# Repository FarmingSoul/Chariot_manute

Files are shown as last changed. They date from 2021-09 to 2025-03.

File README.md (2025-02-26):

# Projet du chariot de manutention
01/09/2021

Ce chariot de manutention à 2 roues centrales. Ce qui lui permet de transporter du poids sans l'aide de l'utilisateur-rice, qui n' a ici plus que le déplacement à gérer.

Ce chariot fut proposé comme solution à une demande de déplacement de poids et volume avec le moindre effort.

chariot

* la surface utile est 200X60 (pour 5 caisse de 60X40 par étage)
* Il y a un tableau à l'avant et des blocages de part et d'autre afin de sécuriser le chargement
* Les roues sont des roues increvables
* Le modèle est paramétrable à la taille de l'utilisateur pour un confort optimal

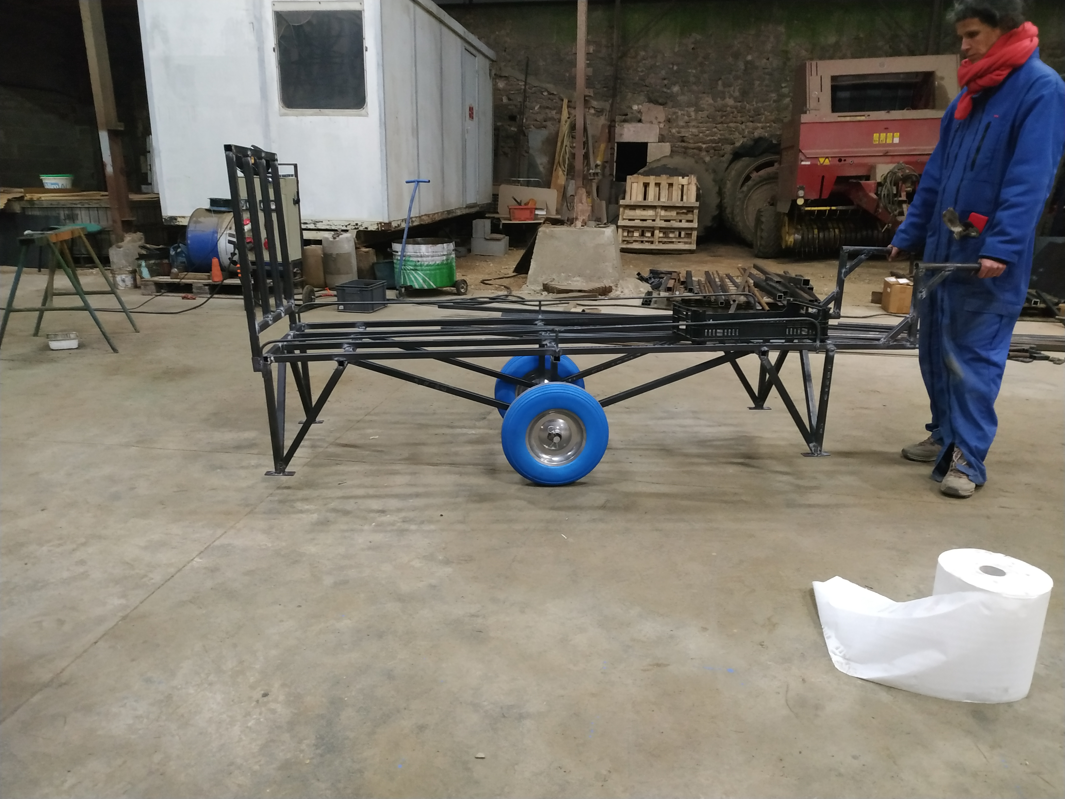
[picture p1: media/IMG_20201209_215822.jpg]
chariot2


# Feuille de route

* modéliser l'outil (fait)
* faire les plans (en cours)
* produire une nomenclature (fait)
* proposé une fiche de débit
* prototyper l'outil (fait)
* média (en cours)
* retours utilisateurs-trices (en cours-dans l'onglet issue)

## pour ouvrir ce modèle sous FreeCAD il est possible que vous ayez besoin du Mod FS
### https://github.com/FarmingSoul/FreeCAD_Mod_FS

### https://FARMINGSOUL.ORG

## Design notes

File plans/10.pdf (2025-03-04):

01/03/25 | 10/16

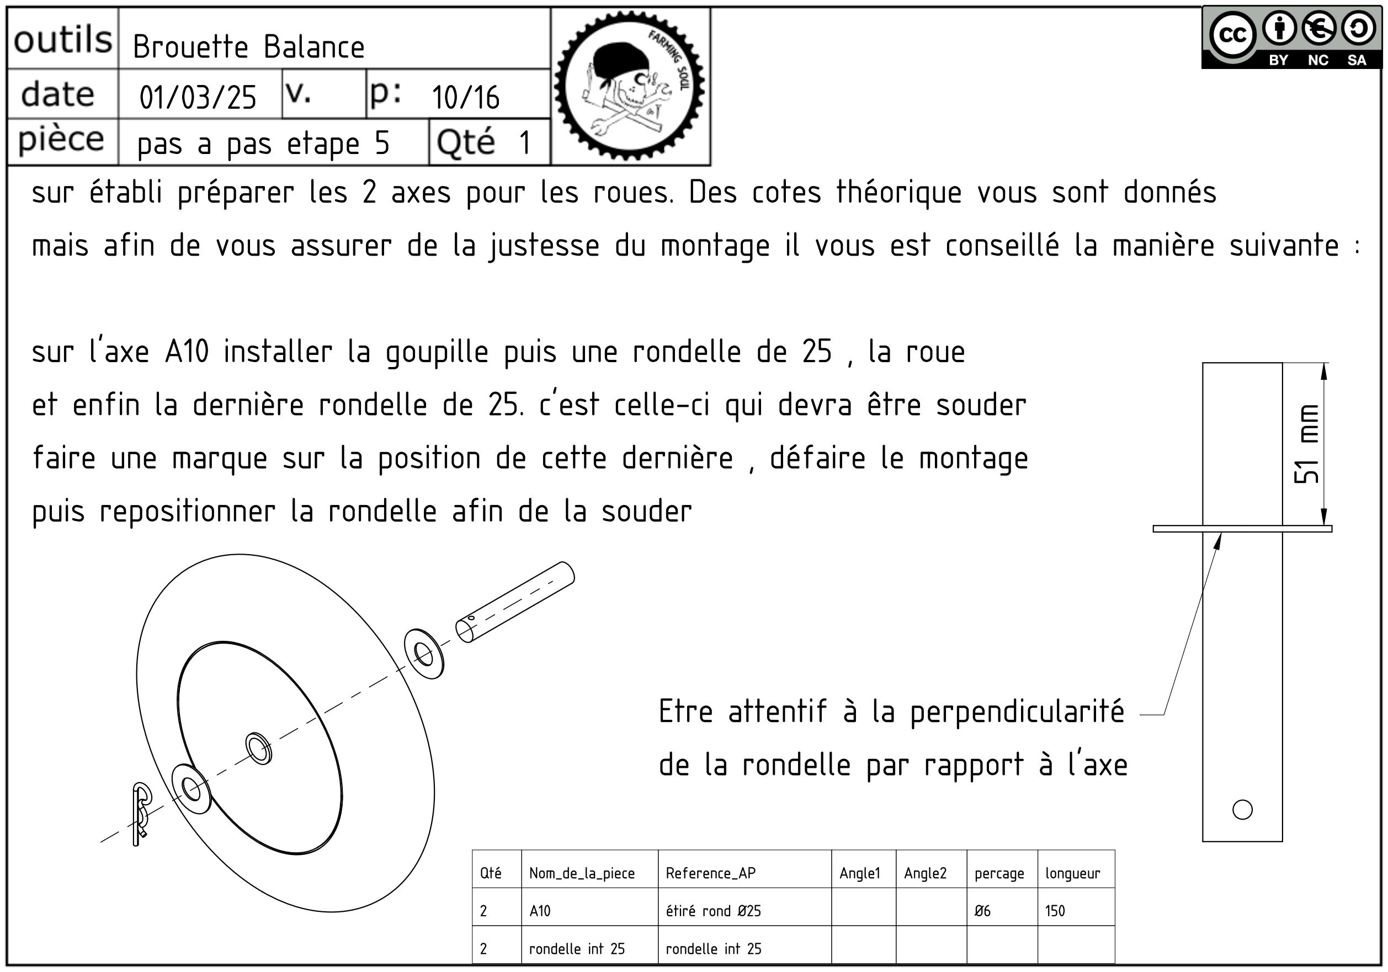
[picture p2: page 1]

51 m

m

sur établi préparer les 2 axes pour les roues. Des cotes théorique vous sont donnés

mais afin de vous assurer de la justesse du montage il vous est conseillé la manière suivante :

sur l'axe A10 installer la goupille puis une rondelle de 25 , la roue

et enfin la dernière rondelle de 25. c'est celle-ci qui devra être souder

faire une marque sur la position de cette dernière , défaire le montage

puis repositionner la rondelle afin de la souder

Brouette Balance

pas a pas etape 5 | 1

Etre attentif à la perpendicularité

de la rondelle par rapport à l'axe

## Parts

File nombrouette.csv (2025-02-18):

Nom_de_la_piece | Reference_AP | Angle1 | Angle2 | percage | longueur | Qty.
A2 | Tube carré 25 x 2 |  |  |  | 610 | 4
A1 | Tube carré 25 x 2 |  |  |  | 2285 | 2
A3 | fer rond Ø10 |  |  |  | 2140 | 2
A4 | fer rond Ø10 |  |  |  | 90 | 2
A5 | Tube carré 25 x 2 |  |  |  | 258.5 | 2
A6 | Tube carré 25 x 2 |  |  |  | 420 | 1
A7 | Tube carré 25 x 2 |  |  |  | 1960 | 2
A8 | Tube carré 25 x 2 |  |  |  | 560 | 1
A9 | Tube carré 25 x 2 |  |  |  | 215 | 2
A12 | Tube carré 25 x 2 |  |  |  | 400 | 4
A13 | Tube carré 25 x 2 | 33.49 | 56.51 |  | 449.6463198543509 | 4
A14 | Tube carré 25 x 2 | 19.66 | 19.66 |  | 772.8352494190133 | 4
A11 | UPN 30 x 15 |  |  |  | 46 | 2
A10 | fer rond Ø25 |  |  |  | 150 | 2
roue | Roue increvable Ø389 Øaxe25 L 82 |  |  |  |  | 2
A15 | Tube carré 25 x 2 | 30.03 | 59.97 |  | 462 | 4
A16 | Tube carré 30 x 2 |  |  |  | 50 | 2
BB1 | Tube carré 25 x 2 |  |  |  | 685 | 2
BB2 | Tube carré 25 x 2 |  |  |  | 560 | 4
A17 | Tube rond 30 x 2 |  |  |  | 300 | 2
A18 | Tube carré 25 x 2 | 45 | 45 |  | 142 | 4
rondelle 25 | rondelle 25 |  |  |  |  | 4
goupille elastique 5 x 80 | goupille elastique 5 x 80 |  |  |  |  | 2

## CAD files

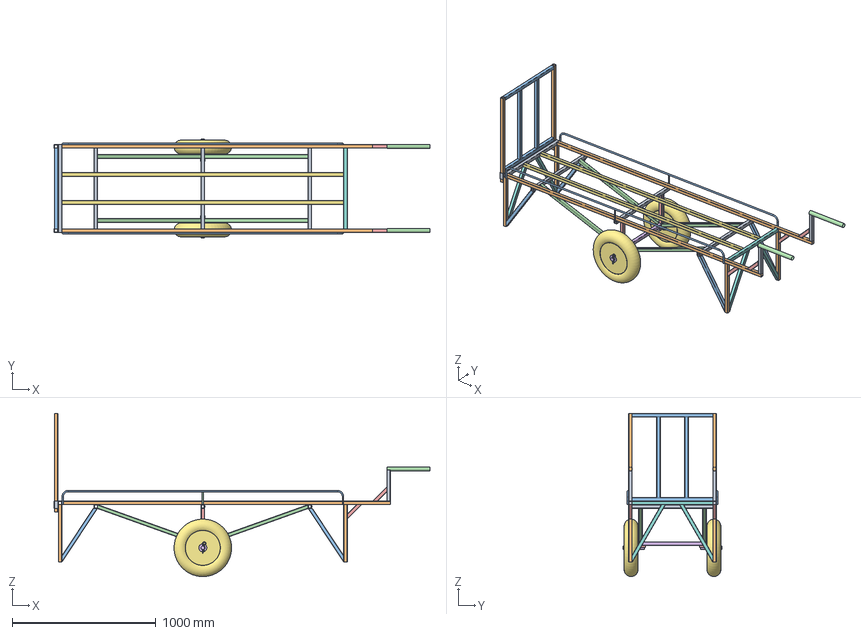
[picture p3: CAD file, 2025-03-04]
brouetteas4-am.FCStd
2615.0 x 688.0 x 1135.0 mm
A8004 x 2
rondellle x 4
goupille x 2

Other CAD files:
brouetteas4.FCStd

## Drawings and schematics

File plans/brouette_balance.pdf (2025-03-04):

2615 mm

01/03/25 | 1/16

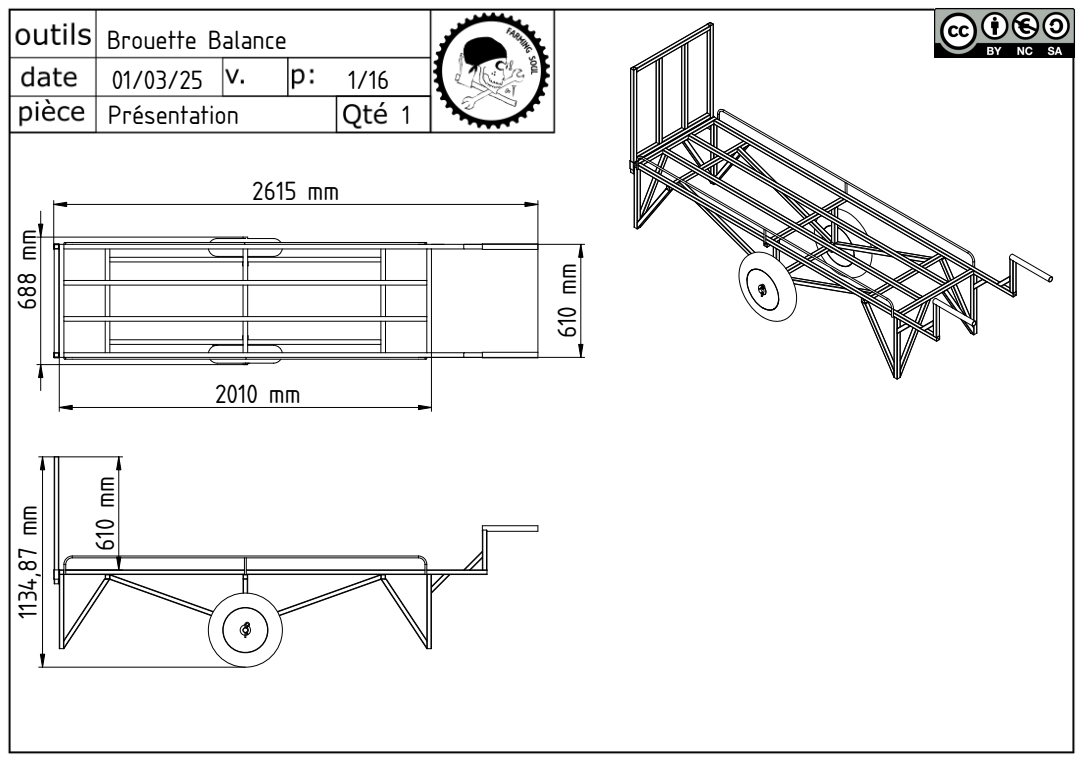
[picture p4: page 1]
Brouette Balance; Présentation

01/03/25 | 2/16

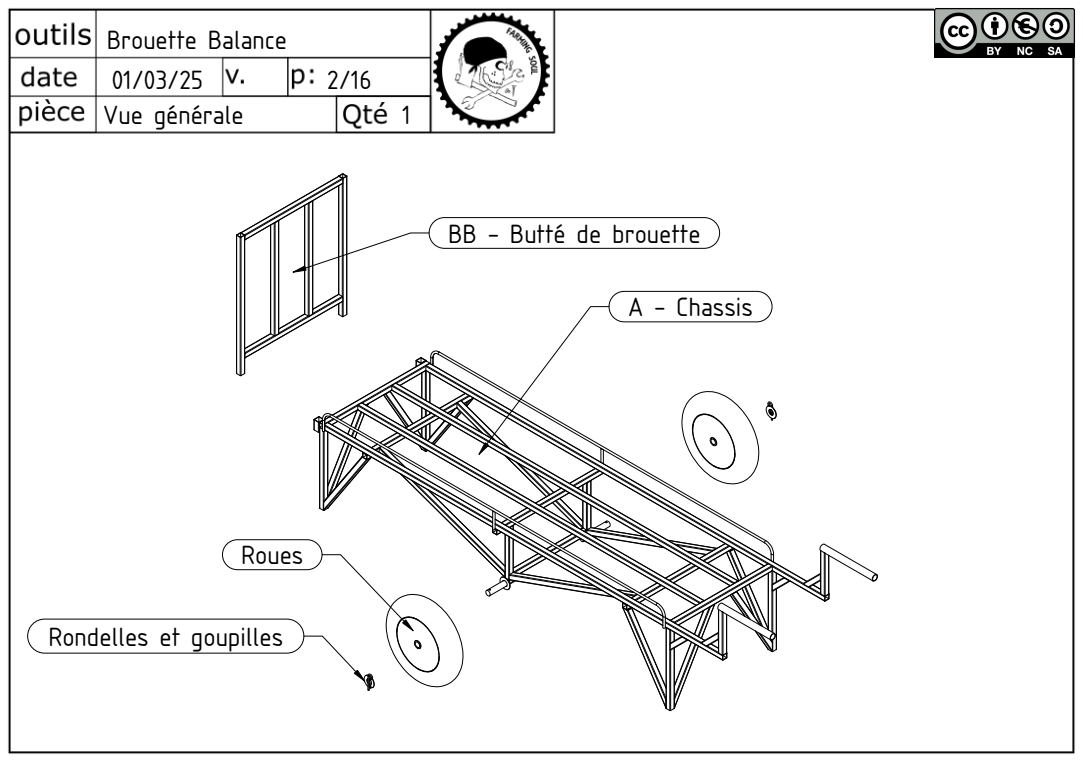
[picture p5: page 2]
A - Chassis; Roues; Vue générale

BB - Butté de brouette

Rondelles et goupilles

A7

01/03/25 | 3/16

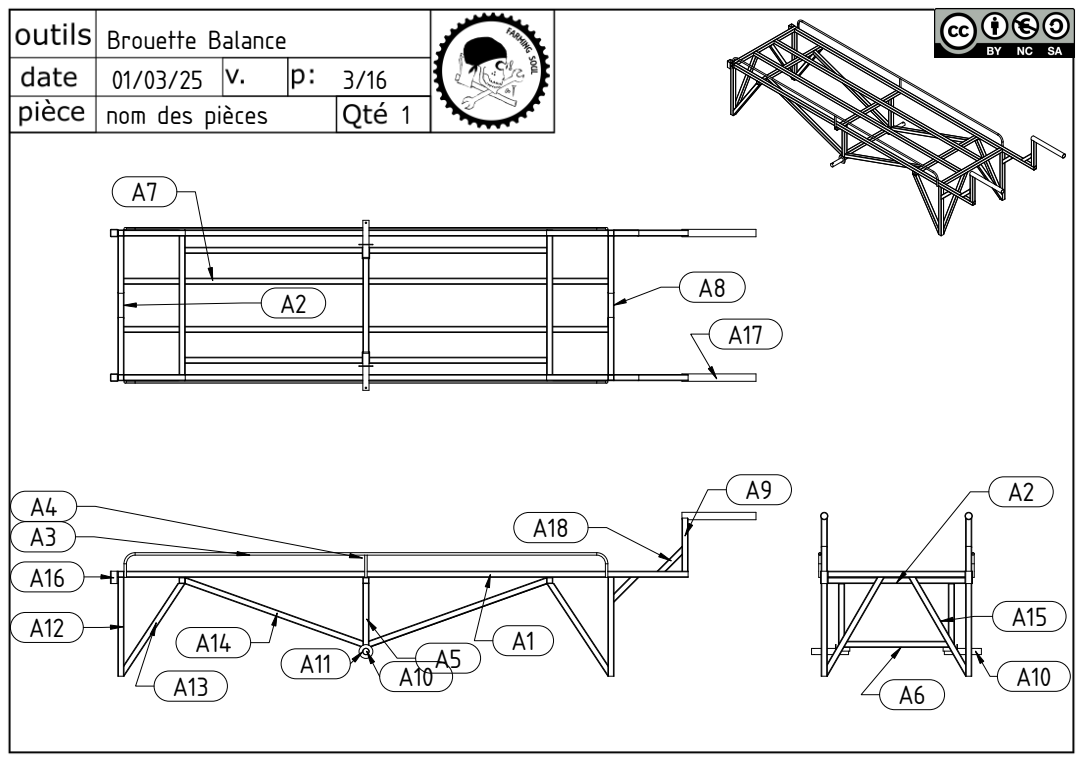
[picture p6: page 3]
nom des pièces

248 mm
992,5 mm

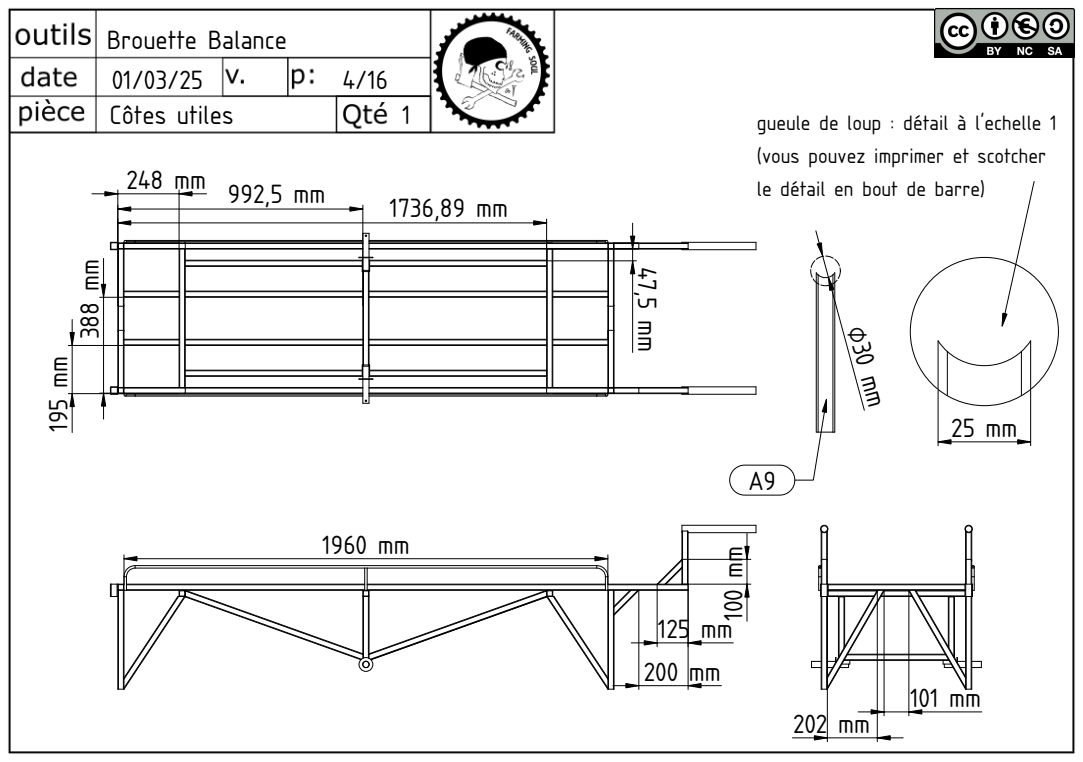
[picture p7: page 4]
Côtes utiles

gueule de loup : détail à l'echelle 1

(vous pouvez imprimer et scotcher

le détail en bout de barre)

195 mm

01/03/25 | 5/16

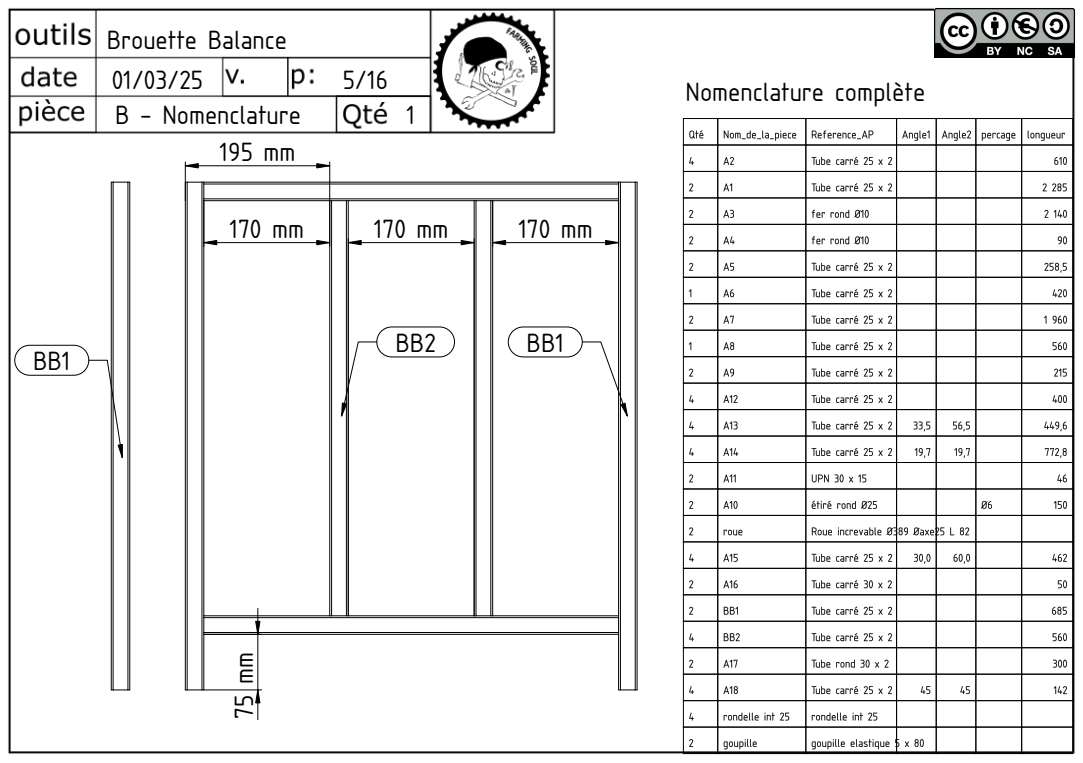
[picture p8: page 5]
Nomenclature complète; B - Nomenclature

A | A8

1

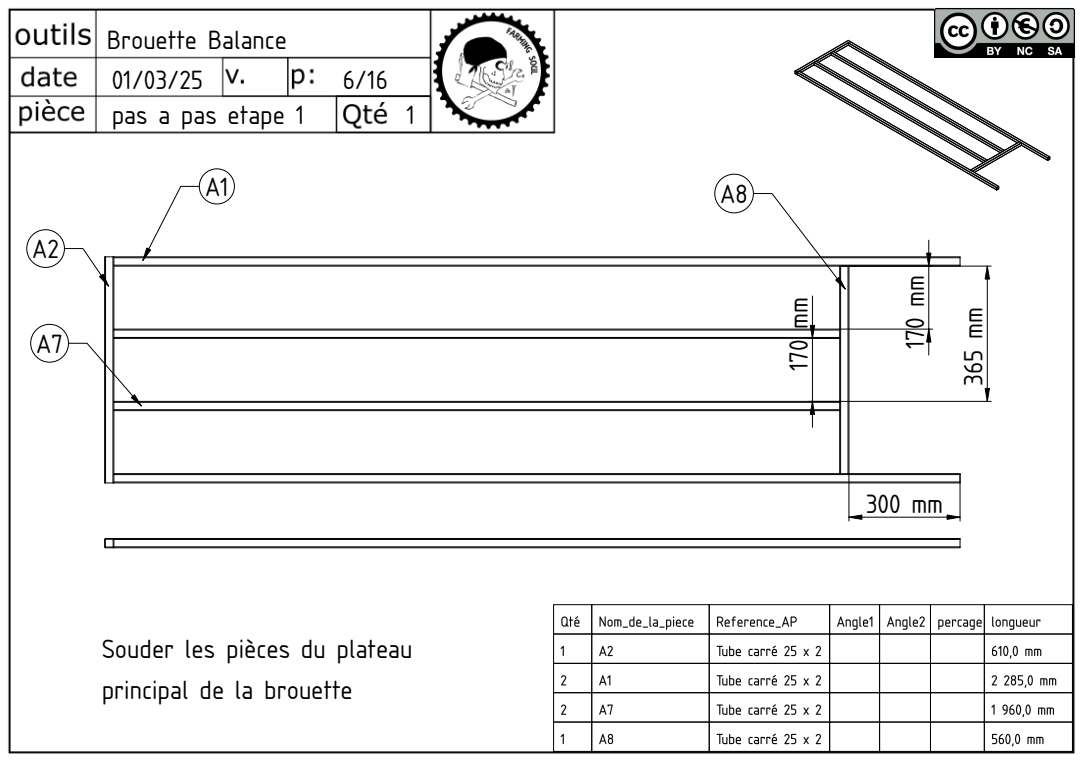
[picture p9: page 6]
pas a pas etape 1

Souder les pièces du plateau

principal de la brouette

01/03/25 | 7/16

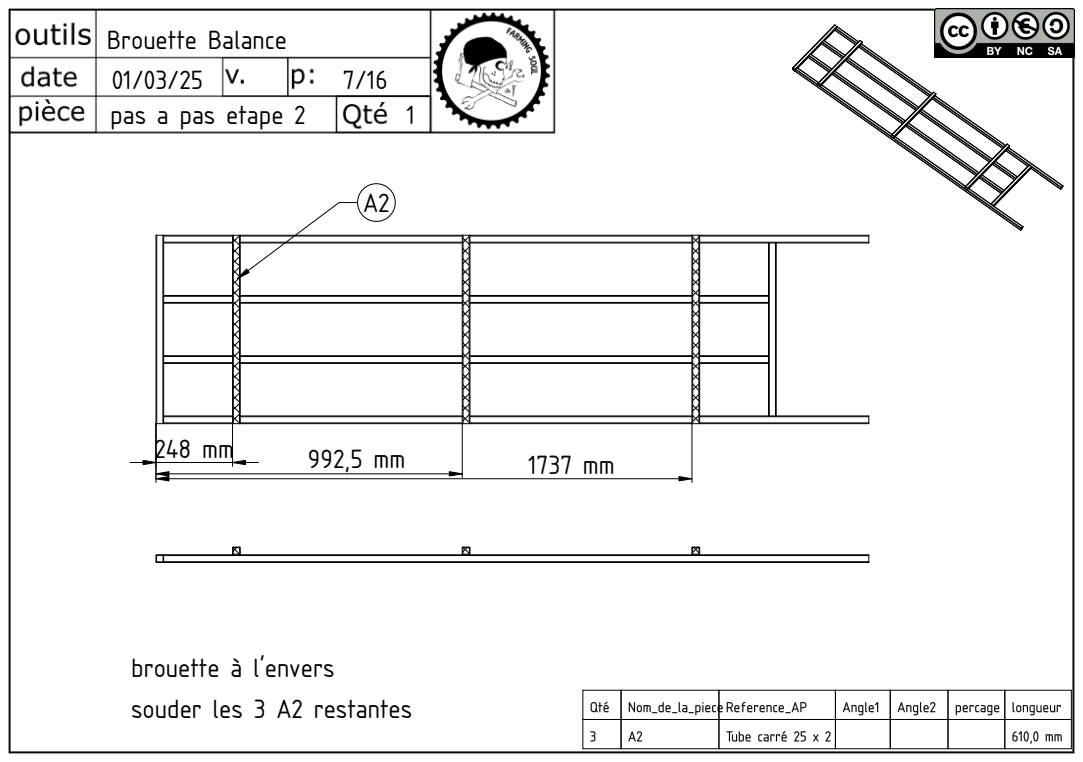
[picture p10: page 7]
brouette à l'envers; pas a pas etape 2

souder les 3 A2 restantes

01/03/25 | 8/16

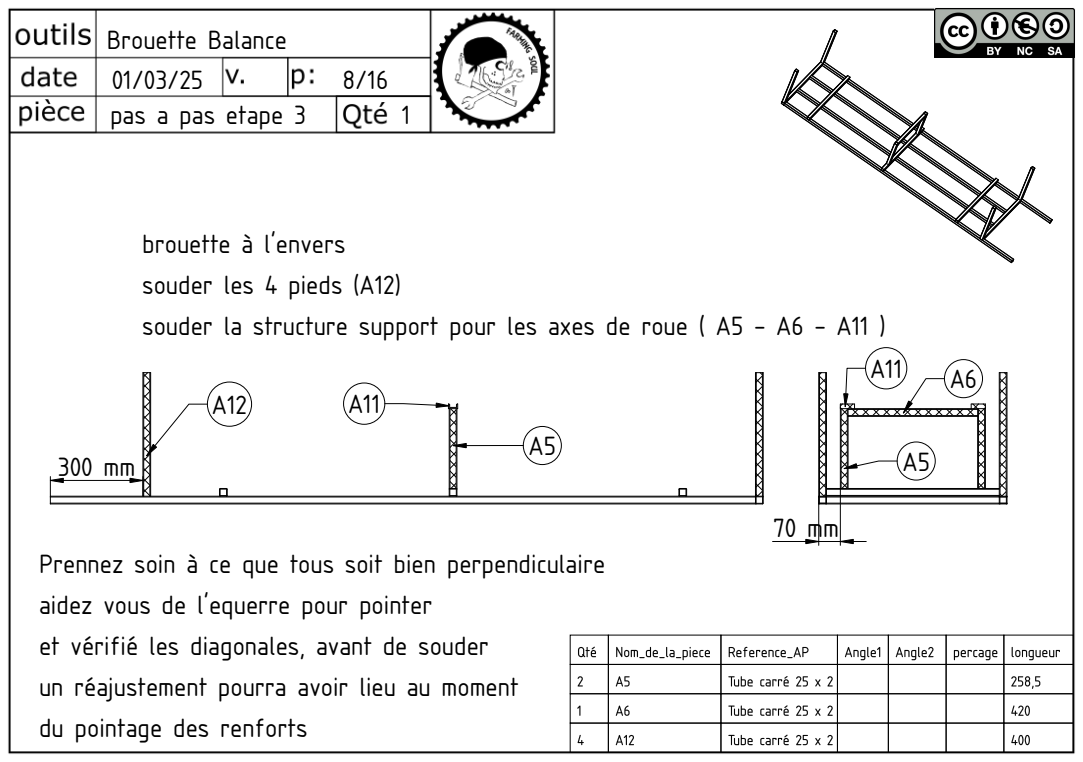
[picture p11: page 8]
brouette à l'envers; pas a pas etape 3

souder les 4 pieds (A12)

souder la structure support pour les axes de roue ( A5 - A6 - A11 )

Prennez soin à ce que tous soit bien perpendiculaire

aidez vous de l'equerre pour pointer

et vérifié les diagonales, avant de souder

un réajustement pourra avoir lieu au moment

du pointage des renforts

01/03/25 | 9/16

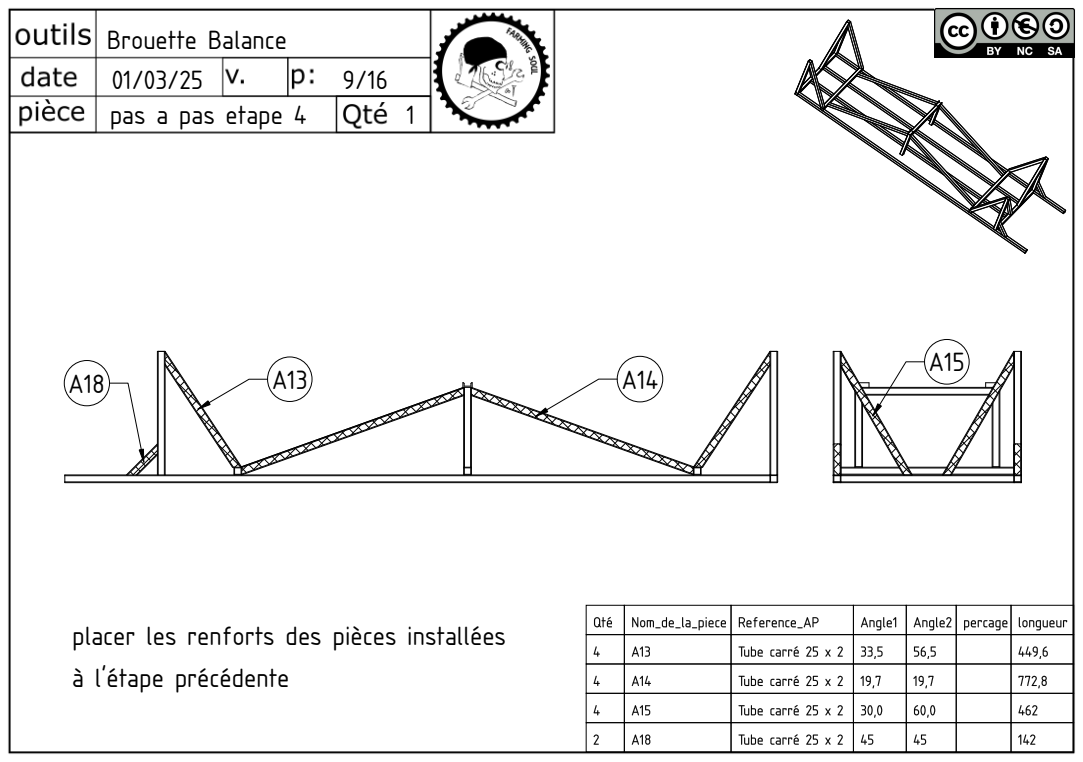
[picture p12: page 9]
à l'étape précédente; pas a pas etape 4

placer les renforts des pièces installées

sur établi préparer les 2 axes pour les roues. Des cotes théorique vous sont donnés

mais afin de vous assurer de la justesse du montage il vous est conseillé la manière suivante :

sur l'axe A10 installer la goupille puis une rondelle de 25 , la roue

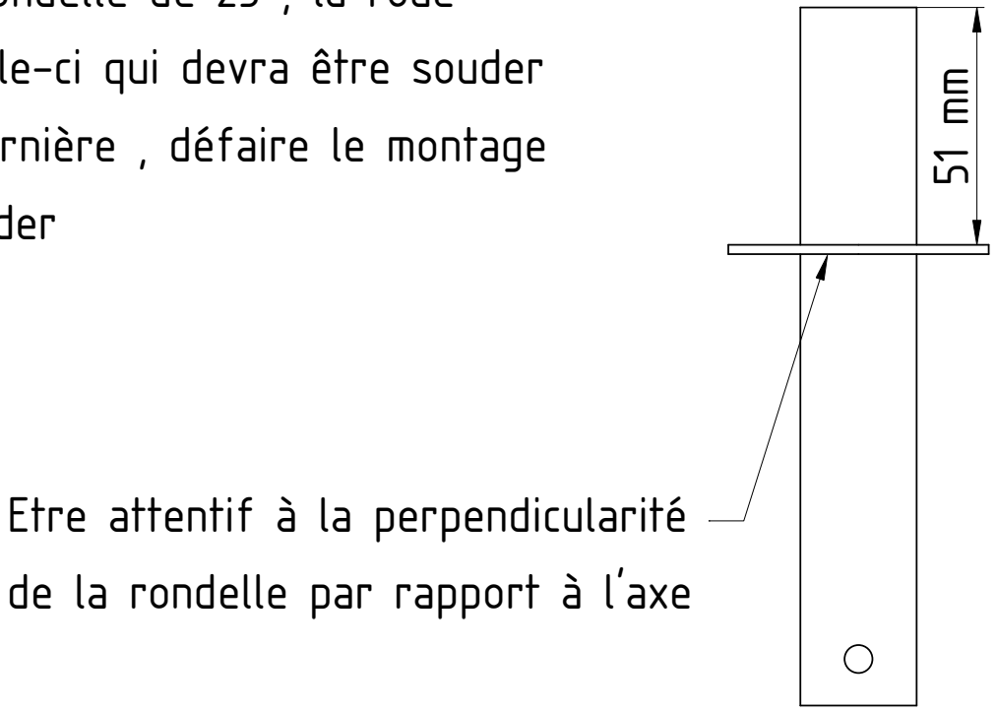
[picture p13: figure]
Etre attentif à la perpendicularité; de la rondelle par rapport à l'axe

et enfin la dernière rondelle de 25. c'est celle-ci qui devra être souder

faire une marque sur la position de cette dernière , défaire le montage

puis repositionner la rondelle afin de la souder

01/03/25 | 10/16
pas a pas etape 5 | 1

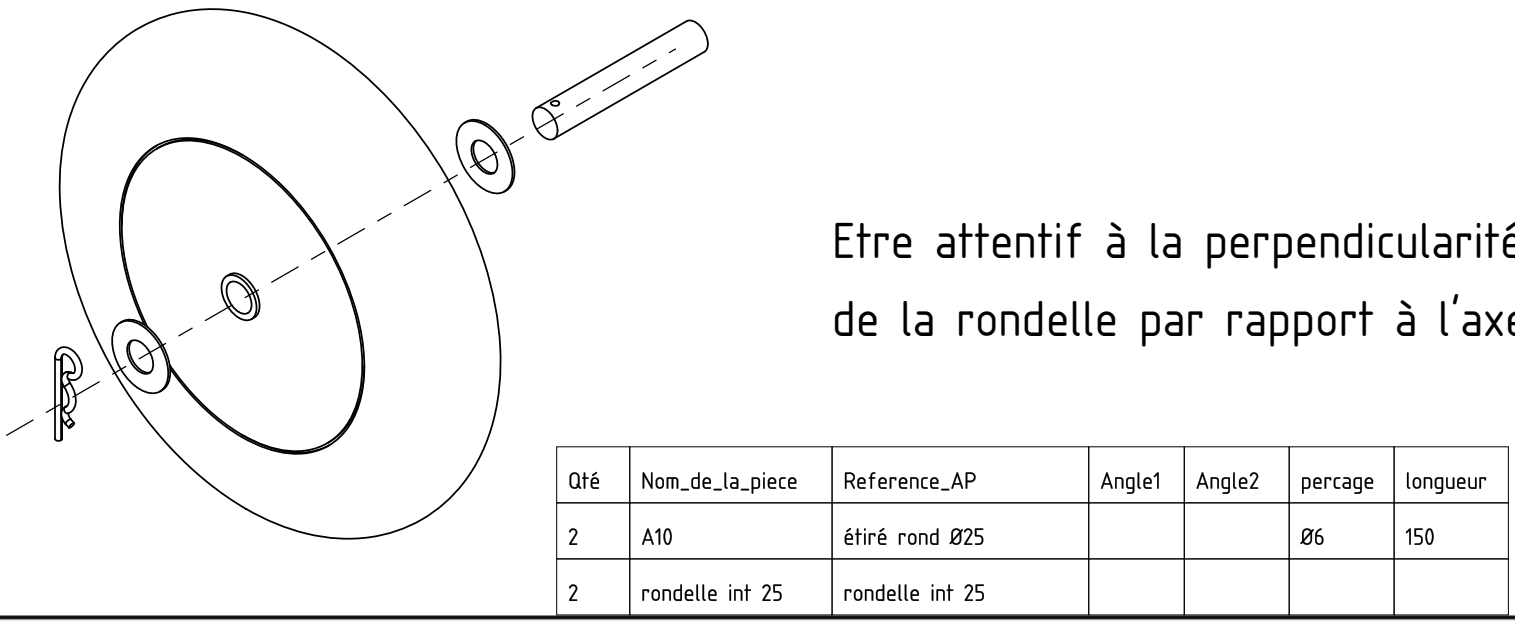
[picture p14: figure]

01/03/25 | 11/16

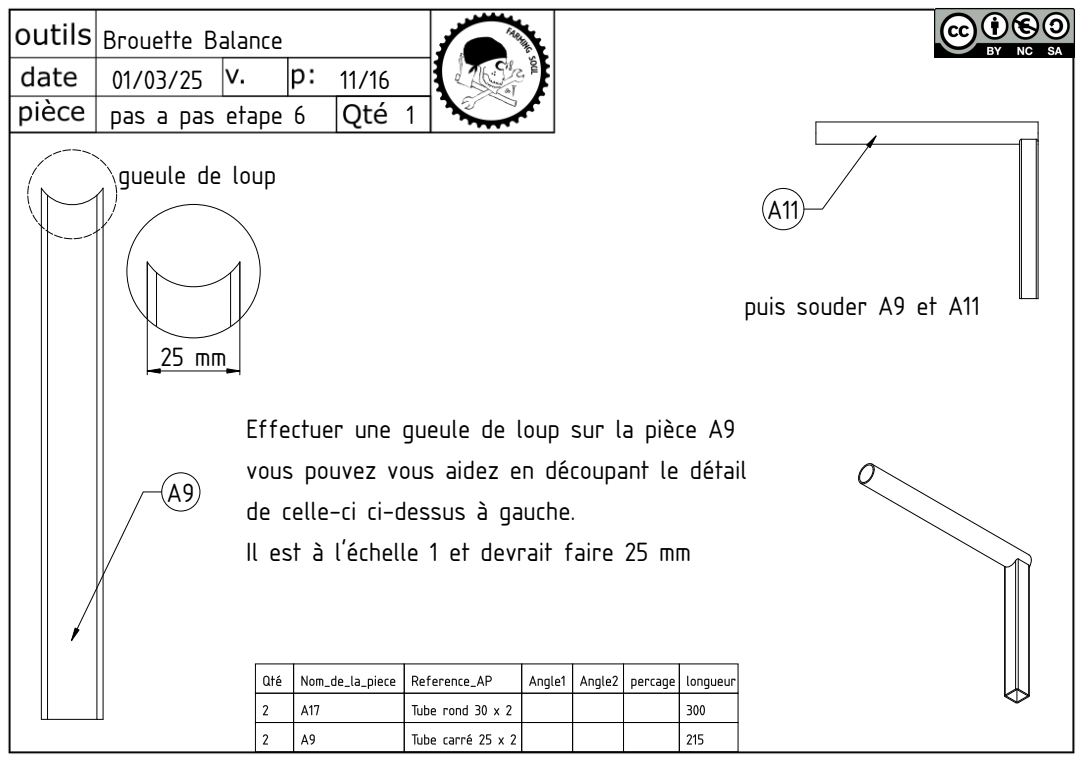
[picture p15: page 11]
pas a pas etape 6

gueule de loup

puis souder A9 et A11

Effectuer une gueule de loup sur la pièce A9

vous pouvez vous aidez en découpant le détail

de celle-ci ci-dessus à gauche.
Il est à l'échelle 1 et devrait faire 25 mm

01/03/25
12/16

zoom

pas a pas etape 7

souder les 2 axes de roue préparés précédement
sur les UPN A10

Respecter un espacement

de 10 mm entre
le bout de la pièce A10

Axe de roue

et la rondelle

1960 mm
1870 mm

précédement construitent; pas a pas etape 8

Souder les poignets

ainsi que leurs renforts

tordre A3 puis souder A3 et A4

sur les paroies exterieur de la brouette

01/03/25 | 14/16

pas a pas etape 9

souder les pièces du fond de la brouette

01/03/25 | 15/16

puis soudez; pas a pas etape 10

pointez les pièces A16

puis installez le fond de brouette

afin de vous assurez que

les pièces A16 soient au bon endroit

01/03/25 | 16/16

maintenant opérationel !; pas a pas etape 11

Il ne vous reste plus qu'a installer les roues - rondelles - goupilles

Votre brouette est

S'il vous plait faite

nous des retours :

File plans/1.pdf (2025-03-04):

2615 mm

01/03/25 | 1/16

Brouette Balance; Présentation

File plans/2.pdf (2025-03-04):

01/03/25 | 2/16

A - Chassis; Roues; Brouette Balance; Vue générale

BB - Butté de brouette

Rondelles et goupilles

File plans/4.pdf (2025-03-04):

248 mm
992,5 mm

Brouette Balance; Côtes utiles

gueule de loup : détail à l'echelle 1

(vous pouvez imprimer et scotcher

le détail en bout de barre)

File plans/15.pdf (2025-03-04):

01/03/25 | 15/16

puis soudez; Brouette Balance; pas a pas etape 10

pointez les pièces A16

puis installez le fond de brouette

afin de vous assurez que

les pièces A16 soient au bon endroit

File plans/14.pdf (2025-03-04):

01/03/25 | 14/16

Brouette Balance; pas a pas etape 9

souder les pièces du fond de la brouette

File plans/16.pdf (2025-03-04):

01/03/25 | 16/16

maintenant opérationel !; Brouette Balance; pas a pas etape 11

Il ne vous reste plus qu'a installer les roues - rondelles - goupilles

Votre brouette est

S'il vous plait faite

nous des retours :

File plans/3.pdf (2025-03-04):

Brouette Balance; nom des pièces

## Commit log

2021-09-01 apport de départ
    modèle 3d-freecad
    nomenclature
    média
    début de présentation
    [brouetteas4.FCStd, nombrouette.csv, nombrouette.ods]
2021-09-01 Update README.md
    ajout des photos
    et de l'avertissement Mod FS
2021-09-01 média to media
    suppression de l'accent à média
2025-02-18 ajout plan
    [brouetteas4.FCStd]
2025-02-18 maj nomenclature
    [brouetteas4.FCStd, nombrouette.csv, nombrouette.ods]
2025-02-26 avancé plan
    [brouetteas4-am.FCStd]
2025-03-01 ajout d'un pas a pas pour l'autoconstruction
    [brouetteas4-am.FCStd]
2025-03-04 plans finaux + export pdf
    [brouetteas4-am.FCStd]
2025-03-04 maj page15
    [brouetteas4-am.FCStd]
